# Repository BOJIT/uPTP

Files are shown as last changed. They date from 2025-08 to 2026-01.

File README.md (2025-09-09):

# uPTP

The smallest, cheapest PTP clock that you can make!

## Project Setup

1. Clone Project to your computer

2. Ensure that you have west installed somehere (I usually put it in `<GIT_REPO>/.venv`, as VSCode will usually launch it automatically.)

- `python -m venv .venv`
- `source .venv/bin/activate`
- `pip install west`

3. Run West Init Locally against the West YAML file: `west init -l software/app

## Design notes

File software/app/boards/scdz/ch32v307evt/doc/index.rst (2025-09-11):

.. zephyr:board:: ch32v307evt

Overview
********

The `SCDZ`_ CH32V307EVT hardware provides support for QingKe V4F 32-bit RISC-V
processor.

The `WCH webpage on CH32V307`_ contains
the processor's information and the datasheet.

Hardware
********

The QingKe V4F 32-bit RISC-V processor of the SCDZ CH32V307EVT is clocked by an external
8 MHz crystal or the internal 8 MHz oscillator and runs with 127 MHz.
The CH32V307 SoC features 8 USART, 5 GPIO banks, 3 SPI, 2 I2C, 2 ADC, RTC,
2 CAN, USB Host/Device, Ethernet and 4 OPA.

Supported Features
==================
- GPIO
- USART

Connections and IOs
===================

LED
---

* LED1 = Unconnected. Connect to an I/O pin (PD0).
* LED2 = Unconnected. Connect to an I/O pin (PD1).

BUTTON
------

* USER0 = Unconnected. Connect to an I/O pinn (PC0).

.. zephyr:board-supported-hw::

Programming and Debugging
*************************

Applications for the ``ch32v307evt`` board target can be built and flashed
in the usual way (see :ref:`build_an_application` and :ref:`application_run`
for more details); however, an external programmer (like the `WCH LinkE`_) is required since the board
does not have any built-in debug support.

The following pins of the external programmer must be connected to the
following pins on the PCB (best way is to use a ribbon cable):

* VCC = VCC (do not power the board from the USB port at the same time)
* GND = GND
* SWDIO = PA13
* SWCLK = PA14

Flashing
========

You can use ``minichlink`` to flash the board. Once ``minichlink`` has been set
up, build and flash applications as usual (see :ref:`build_an_application` and
:ref:`application_run` for more details).

Here is an example for the :zephyr:code-sample:`hello_world` application.

.. zephyr-app-commands::
   :zephyr-app: samples/hello_world
   :board: ch32v307evt
   :goals: build flash

Debugging
=========

This board can be debugged via OpenOCD using the WCH openOCD liberated fork, available at https://github.com/jnk0le/openocd-wch.

References
**********

.. target-notes::

.. _WCH: http://www.wch-ic.com
.. _WCH webpage on CH32V307: https://www.wch-ic.com/products/CH32V307.html
.. _WCH LinkE: https://www.wch-ic.com/products/WCH-Link.html

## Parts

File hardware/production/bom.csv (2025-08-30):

Designator | Footprint | Quantity | Value | LCSC Part #
C1, C15 | 0603 | 2 | 10u | C19702
C10, C16, C17, C18, C19, C2, C20, C21, C22, C25, C6, C7 | 0402 | 12 | 100n | C1525
C11, C9 | 0805 | 2 | 10u | C440198
C12 | 0402 | 1 | 1n | C1523
C13, C14 | 1206 | 2 | 100u | C15008
C23, C24 | 0402 | 2 | 20p | C1554
C3 | 0402 | 1 | 2.2u | C12530
C4 | 1206 | 1 | 1n | C9196
C5, C8 | 0805 | 2 | 100n | C28233
D1, D2, D3 | D_SOD-323 | 3 | BAT60JFILM | C133103
D4 | LED_WS2812B-2020_PLCC4_2.0x2.0mm | 1 | WS2812B-2020 | C965555
D5, D6 | DIO-BG-SMD_4P-L4.9-W4.0-P2.54-LS7.0-BR | 2 | MB10F_C2491 | C2491
D7, D8 | D_SMA | 2 | SS210 | C14996
D9 | SOT-23-6_L2.9-W1.6-P0.95-LS2.8-BL | 1 | USBLC6-2SC6 | C7519
FB1, FB2 | 0603 | 2 | GZ1608D601TF | C1002
J1 | IPEX-SMD_HC-RF-IPEX0303-01 | 1 | PPS_UFL | C2894919
J5 | RJ45-SMD_HC-RJ45-055-7_1 | 1 | HC-RJ45-055-7 | C3000213
L1 | L_Changjiang_FXL0630 | 1 | 47u | C475913
R1, R2, R3, R4, R6 | 0402 | 5 | 75 | C25133
R10 | 0402 | 1 | 1.2 | C2998063
R13, R5 | 0402 | 2 | 24k | C25769
R14 | 0402 | 1 | 4.3k | C25899
R15 | 0402 | 1 | 12k | C25752
R16, R17 | 0402 | 2 | 10k | C25744
R18 | 0402 | 1 | 10 | C25077
R19, R20 | 0402 | 2 | 5.1k | C25905
R7 | 0402 | 1 | 88.7k | C170366
TR1 | B1608S | 1 | Ethernet Magnetics | C507596
U1 | SOT-23-3 | 1 | XC6206P332MR-G | C5446
U2 | QFN-20-1EP_4x4mm_P0.5mm_EP2.6x2.6mm | 1 | SI3404-A-GMR | C461934
U3 | QFN-68_L8.0-W8.0-P0.40-BL-EP6.7 | 1 | CH32V307WCU6 | C5142795
USB1 | USB-C-SMD_TYPE-C-16PIN | 1 | TYPE-C 16PIN 2MD(073) | C2765186
X1 | CRYSTAL-SMD_L5.0-W3.2 | 1 | X50328MSB2GI | C115962

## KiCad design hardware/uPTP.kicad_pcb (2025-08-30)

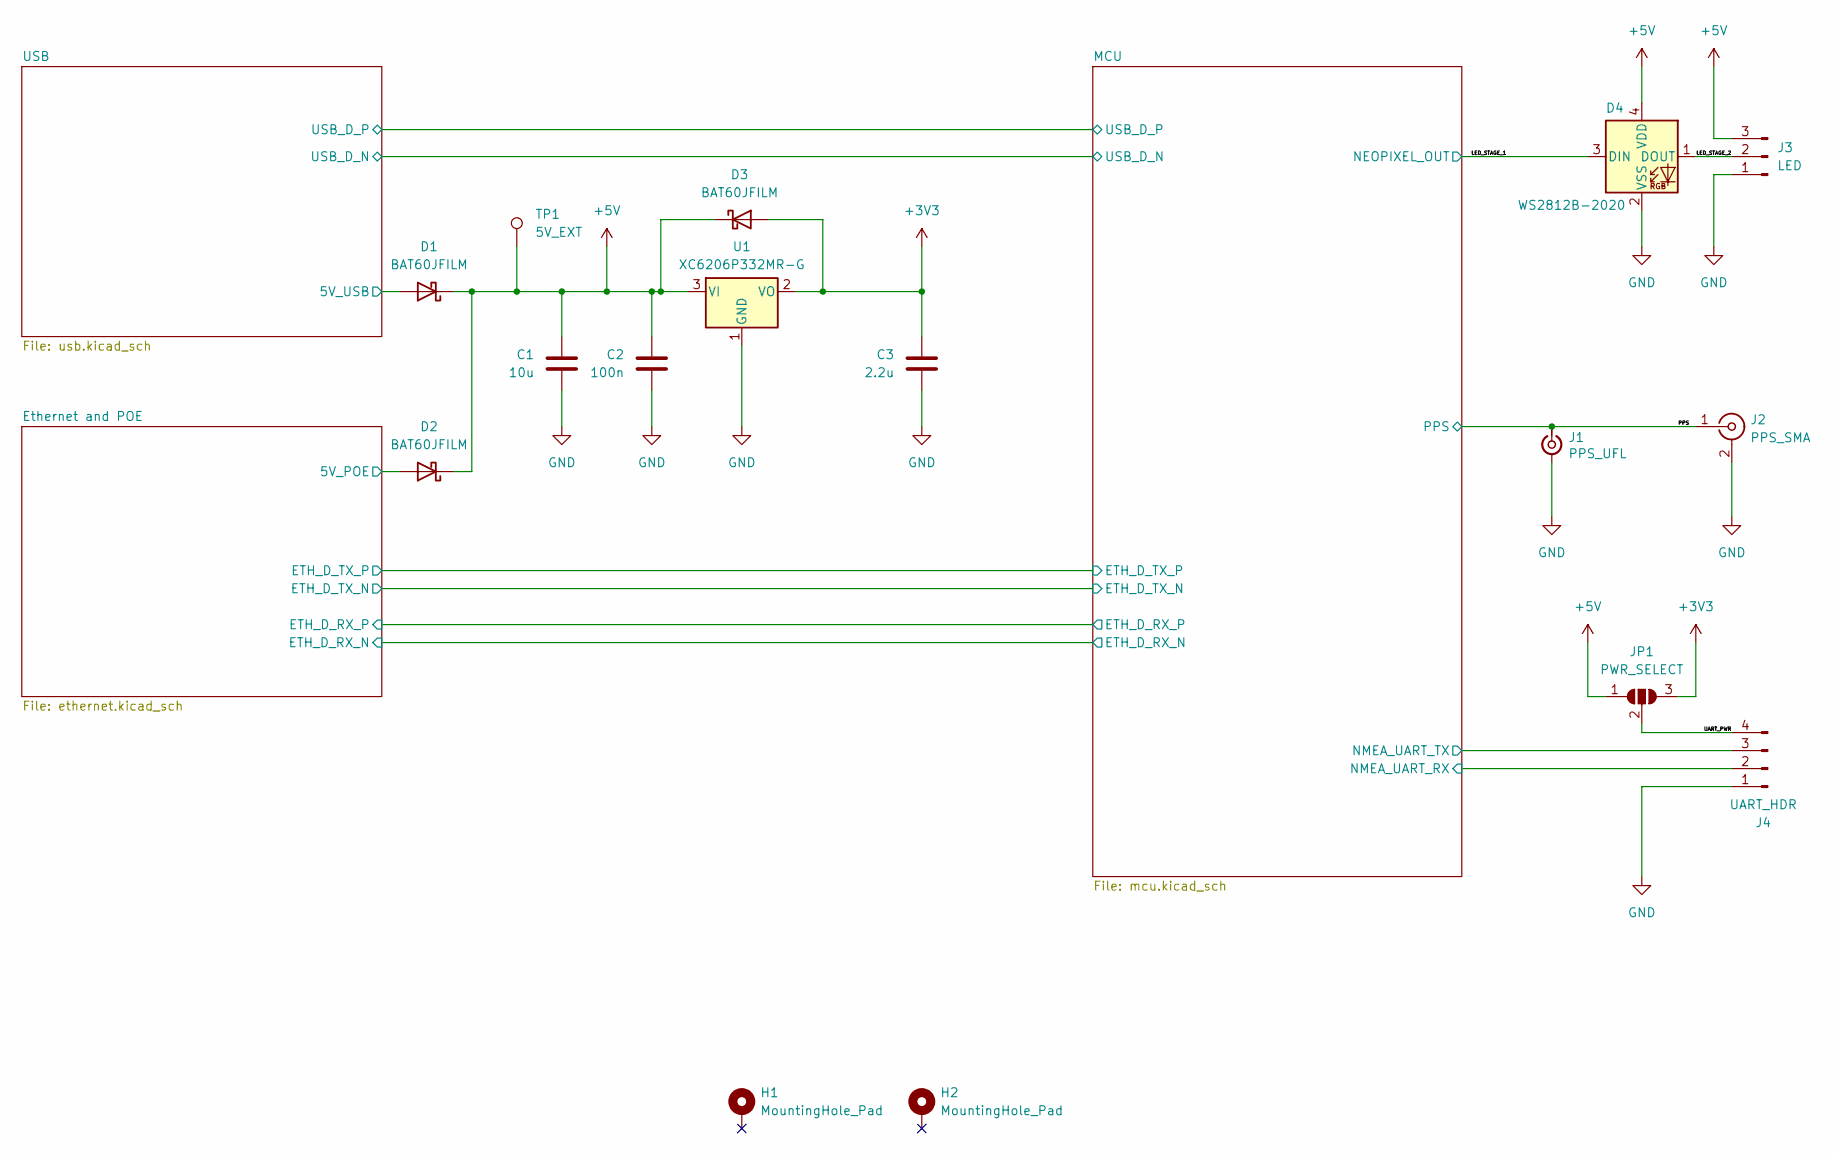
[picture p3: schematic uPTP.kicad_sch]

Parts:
C1: 10u; C_0603_1608Metric; LCSC Part C19702
C2: 100n; C_0402_1005Metric; LCSC Part C1525
C3: 2.2u; C_0402_1005Metric; LCSC Part C12530
D1, D2, D3: BAT60JFILM; D_SOD-323; LCSC Part C133103
D4: WS2812B-2020; LED_WS2812B-2020_PLCC4_2.0x2.0mm; LCSC Part C965555
H1, H2: MountingHole_Pad; MountingHole_3.2mm_M3_Pad
J1: PPS_UFL; IPEX-SMD_HC-RF-IPEX0303-01; LCSC Part C2894919
J2: PPS_SMA; SMA_Samtec_SMA-J-P-H-ST-EM1_EdgeMount
J3: LED; PinHeader_1x03_P1.27mm_Vertical
J4: UART_HDR; PinHeader_1x04_P2.54mm_Horizontal
JP1: PWR_SELECT; SolderJumper-3_P1.3mm_Open_RoundedPad1.0x1.5mm_NumberLabels
TP1: 5V_EXT; TestPoint_Pad_D1.5mm
U1: XC6206P332MR-G; SOT-23-3; LCSC Part C5446

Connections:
+3V3: C3.1, D3.2 (A), JP1.3 (B), U1.2 (VO); also elsewhere on the board
+5V: C1.1, C2.1, D1.1 (K), D2.1 (K), D3.1 (K), D4.4 (VDD), J3.3, JP1.1 (A), TP1.1, U1.3 (VI)
+5V_USB: D1.2 (A); also elsewhere on the board
/Ethernet and POE/ETH_POE_FILT_P: D2.2 (A); also elsewhere on the board
/LED_STAGE_1: D4.3 (DIN); also elsewhere on the board
/LED_STAGE_2: D4.1 (DOUT), J3.2
/MCU/NMEA_UART_RX: J4.2; also elsewhere on the board
/MCU/NMEA_UART_TX: J4.3; also elsewhere on the board
/PPS: J1.1 (In), J2.1 (In); also elsewhere on the board
/UART_PWR: J4.4, JP1.2 (C)
GND: C1.2, C2.2, C3.2, D4.2 (VSS), J1.2 (Ext), J2.2 (Ext), J3.1, J4.1, U1.1 (GND); also elsewhere on the board

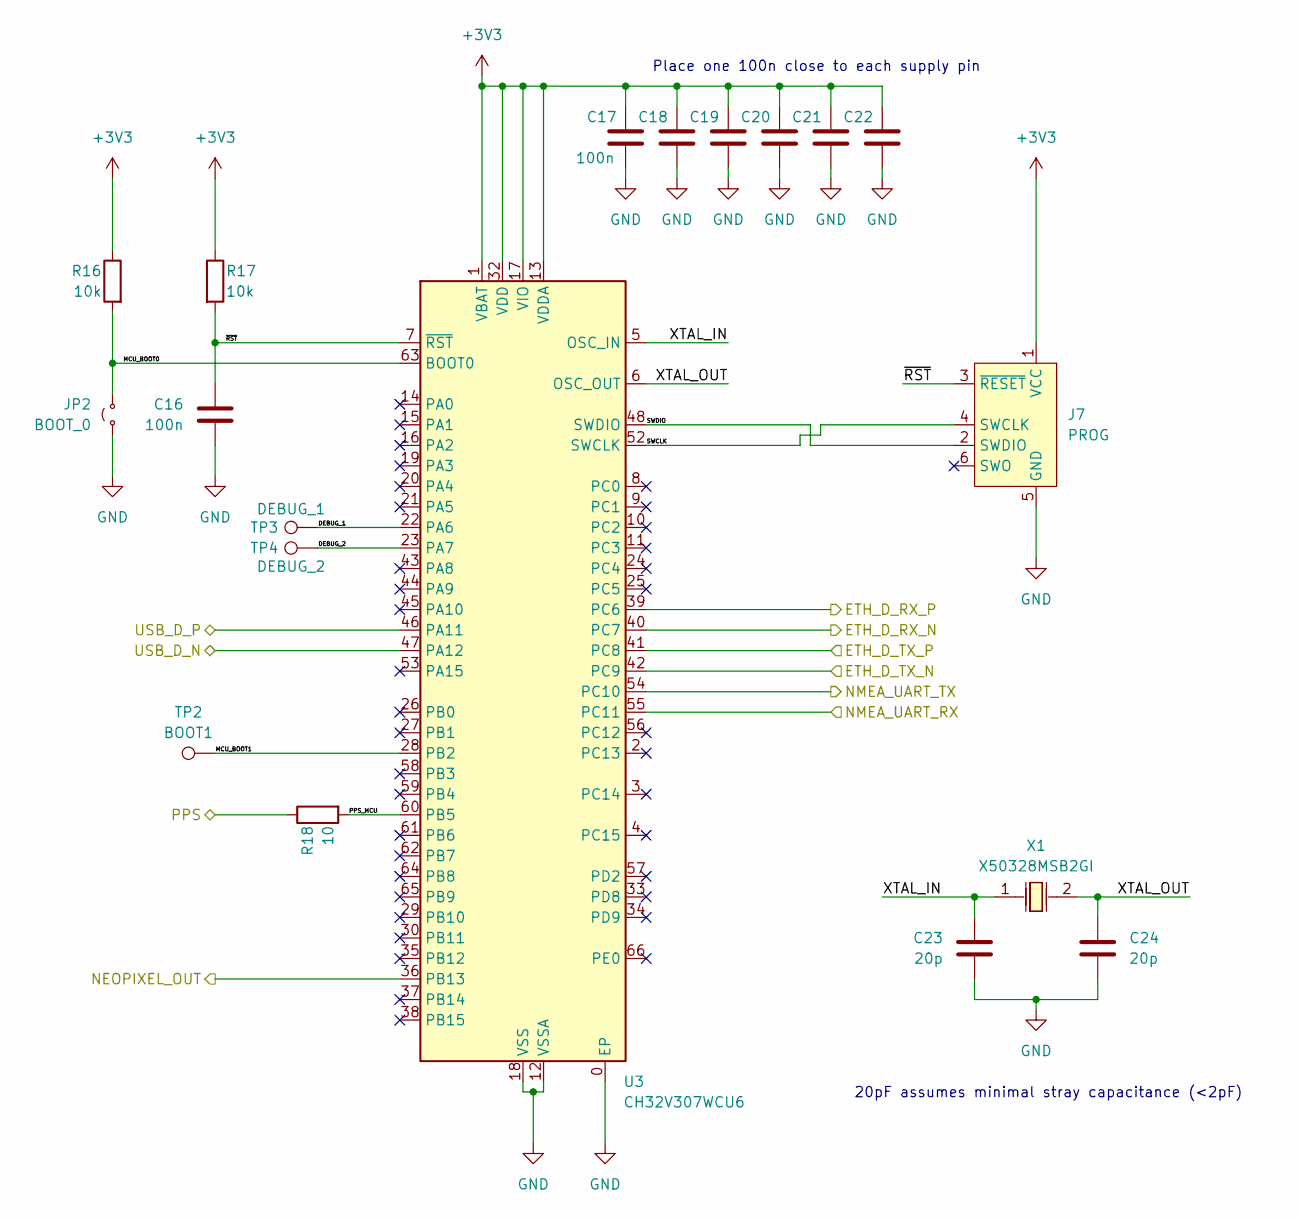
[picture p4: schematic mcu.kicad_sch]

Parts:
C16, C17, C18, C19, C20, C21, C22: 100n; C_0402_1005Metric; LCSC Part C1525
C23, C24: 20p; C_0402_1005Metric; LCSC Part C1554
J7: PROG; Tag-Connect_TC2030-IDC-NL_2x03_P1.27mm_Vertical
JP2: BOOT_0; SolderJumper-2_P1.3mm_Open_RoundedPad1.0x1.5mm
R16, R17: 10k; R_0402_1005Metric; LCSC Part C25744
R18: 10; R_0402_1005Metric; LCSC Part C25077
TP2: BOOT1; TestPoint_Pad_D1.5mm
TP3: DEBUG_1; TestPoint_Pad_D1.5mm
TP4: DEBUG_2; TestPoint_Pad_D1.5mm
U3: CH32V307WCU6; QFN-68_L8.0-W8.0-P0.40-BL-EP6.7; LCSC Part C5142795
X1: X50328MSB2GI; CRYSTAL-SMD_L5.0-W3.2; LCSC Part C115962

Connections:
+3V3: C17.1, C18.1, C19.1, C20.1, C21.1, C22.1, J7.1 (VCC), R16.1, R17.1, U3.1 (VBAT), U3.13 (VDDA), U3.17 (VIO), U3.31 (VIO), U3.32 (VDD), U3.50 (VDD), U3.51 (VIO), U3.67 (VIO), U3.68 (VDD); also elsewhere on the board
/Ethernet and POE/ETH_D_RX_N: U3.40 (PC7); also elsewhere on the board
/Ethernet and POE/ETH_D_RX_P: U3.39 (PC6); also elsewhere on the board
/Ethernet and POE/ETH_D_TX_N: U3.42 (PC9); also elsewhere on the board
/Ethernet and POE/ETH_D_TX_P: U3.41 (PC8); also elsewhere on the board
/LED_STAGE_1: U3.36 (PB13); also elsewhere on the board
/MCU/DEBUG_1: TP3.1, U3.22 (PA6)
/MCU/DEBUG_2: TP4.1, U3.23 (PA7)
/MCU/MCU_BOOT0: JP2.2 (B), R16.2, U3.63 (BOOT0)
/MCU/MCU_BOOT1: TP2.1, U3.28 (PB2)
/MCU/NMEA_UART_RX: U3.55 (PC11); also elsewhere on the board
/MCU/NMEA_UART_TX: U3.54 (PC10); also elsewhere on the board
/MCU/PPS_MCU: R18.2, U3.60 (PB5)
/MCU/SWCLK: J7.4 (SWCLK), U3.52 (SWCLK)
/MCU/SWDIO: J7.2 (SWDIO), U3.48 (SWDIO)
/MCU/USB_D_N: U3.47 (PA12); also elsewhere on the board
/MCU/USB_D_P: U3.46 (PA11); also elsewhere on the board
/MCU/XTAL_IN: C23.1, U3.5 (OSC_IN), X1.1
/MCU/XTAL_OUT: C24.1, U3.6 (OSC_OUT), X1.2
/MCU/~RST: C16.1, J7.3 (~RESET), R17.2, U3.7 (~RST)
/PPS: R18.1; also elsewhere on the board
GND: C16.2, C17.2, C18.2, C19.2, C20.2, C21.2, C22.2, C23.2, C24.2, J7.5 (GND), JP2.1 (A), U3.0 (EP), U3.12 (VSSA), U3.18 (VSS), U3.49 (VSS), U3.69 (VSS); also elsewhere on the board

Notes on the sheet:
20pF assumes minimal stray capacitance (<2pF)
Place one 100n close to each supply pin

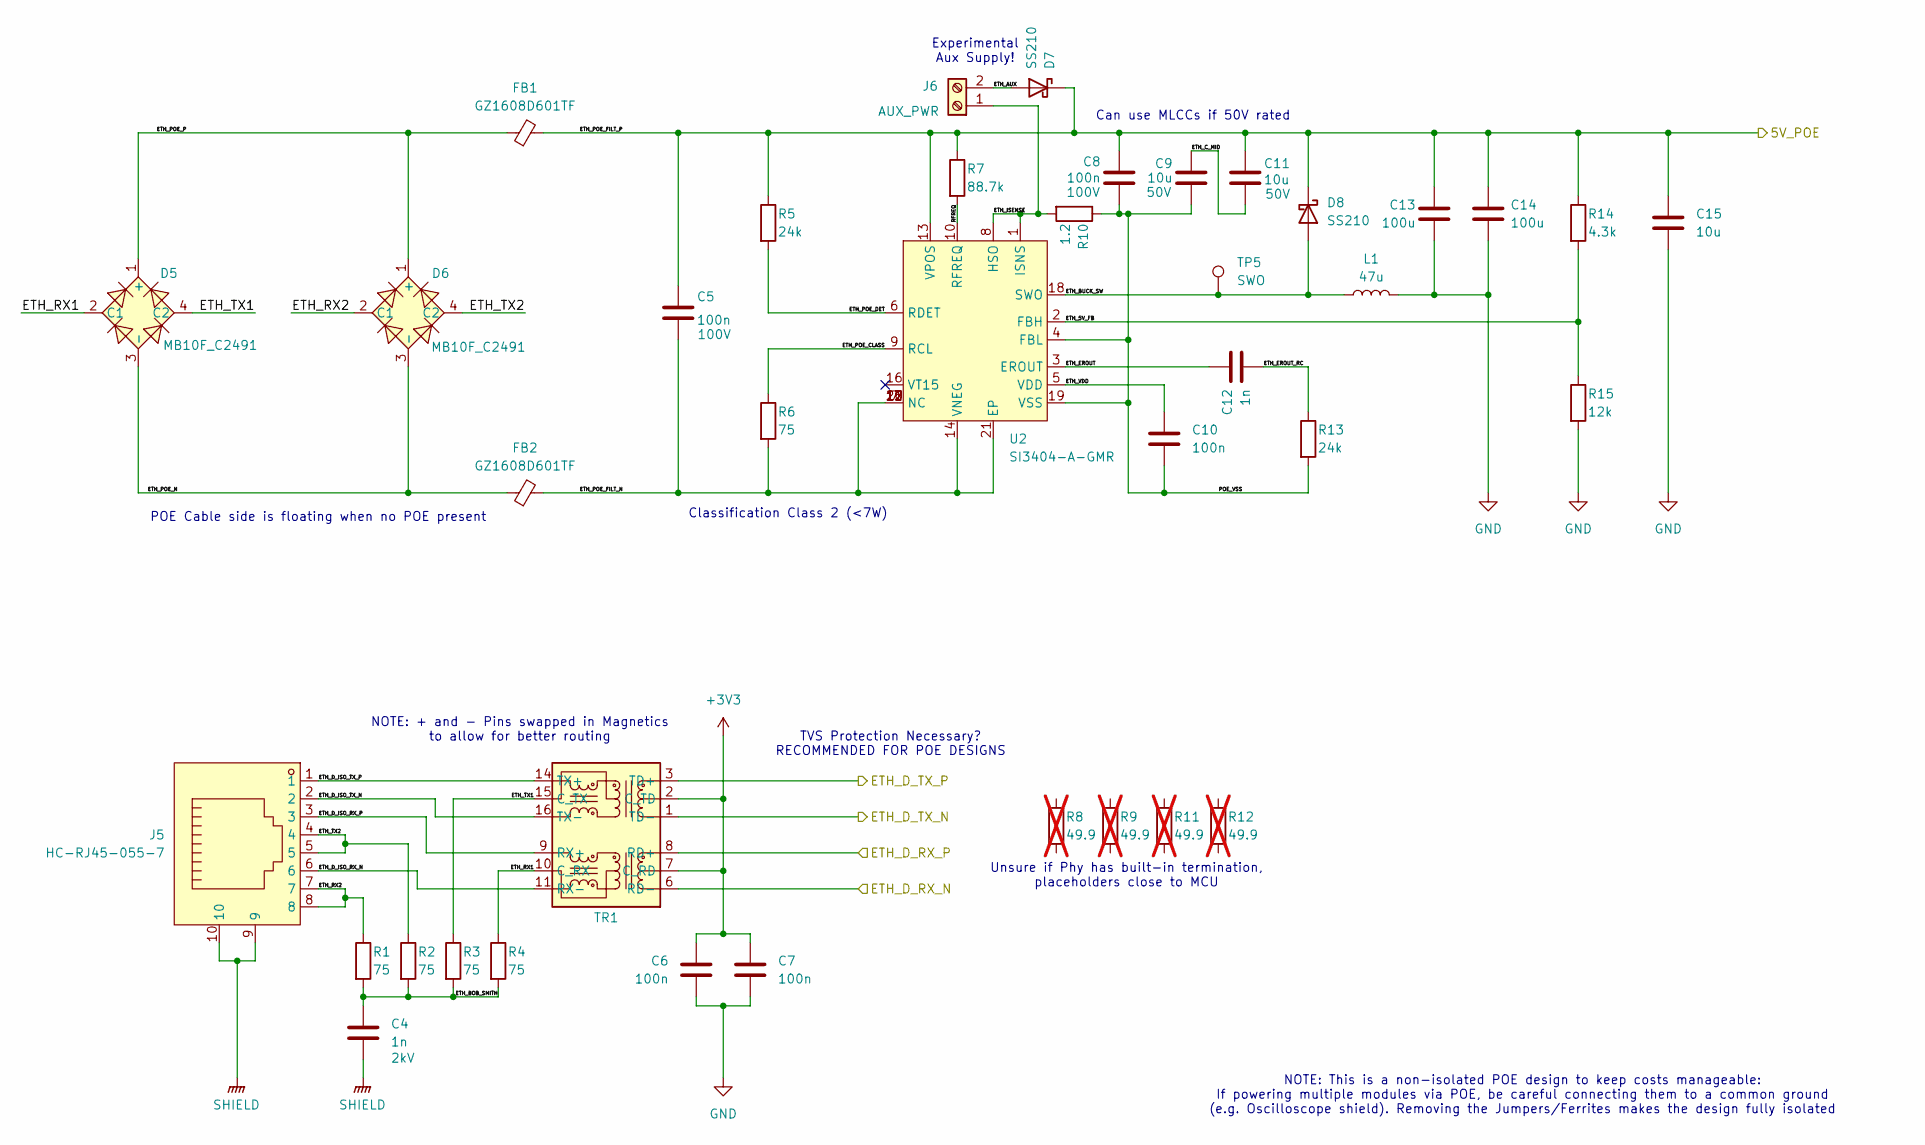
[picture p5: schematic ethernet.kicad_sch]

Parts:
C4: 1n; C_1206_3216Metric; LCSC Part C9196
C5, C8: 100n; C_0805_2012Metric; LCSC Part C28233
C6, C7, C10: 100n; C_0402_1005Metric; LCSC Part C1525
C9, C11: 10u; C_0805_2012Metric; LCSC Part C440198
C12: 1n; C_0402_1005Metric; LCSC Part C1523
C13, C14: 100u; C_1206_3216Metric; LCSC Part C15008
C15: 10u; C_0603_1608Metric; LCSC Part C19702
D5, D6: MB10F_C2491; DIO-BG-SMD_4P-L4.9-W4.0-P2.54-LS7.0-BR; LCSC Part C2491
D7, D8: SS210; D_SMA; LCSC Part C14996
FB1, FB2: GZ1608D601TF; R_0603_1608Metric; LCSC Part C1002
J5: HC-RJ45-055-7; RJ45-SMD_HC-RJ45-055-7_1; LCSC Part C3000213
J6: AUX_PWR; TerminalBlock_Phoenix_MPT-0,5-2-2.54_1x02_P2.54mm_Horizontal
L1: 47u; L_Changjiang_FXL0630; LCSC Part C475913
R1, R2, R3, R4, R6: 75; R_0402_1005Metric; LCSC Part C25133
R5, R13: 24k; R_0402_1005Metric; LCSC Part C25769
R7: 88.7k; R_0402_1005Metric; LCSC Part C170366
R8, R9, R11, R12: 49.9; R_0402_1005Metric; not fitted
R10: 1.2; R_0402_1005Metric; LCSC Part C2998063
R14: 4.3k; R_0402_1005Metric; LCSC Part C25899
R15: 12k; R_0402_1005Metric; LCSC Part C25752
TP5: SWO; TestPoint_Pad_D1.5mm
TR1: Ethernet Magnetics; B1608S; LCSC Part C507596
U2: SI3404-A-GMR; QFN-20-1EP_4x4mm_P0.5mm_EP2.6x2.6mm; LCSC Part C461934

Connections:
+3V3: C6.1, C7.1, TR1.2 (C_TD), TR1.7 (C_RD); also elsewhere on the board
/Ethernet and POE/ETH_5V_FB: R14.2, R15.1, U2.2 (FBH)
/Ethernet and POE/ETH_AUX: D7.2 (A), J6.2
/Ethernet and POE/ETH_BOB_SMITH: C4.1, R1.2, R2.2, R3.2, R4.2
/Ethernet and POE/ETH_BUCK_SW: D8.2 (A), L1.1, TP5.1, U2.18 (SWO)
/Ethernet and POE/ETH_C_MID: C9.1, C11.2
/Ethernet and POE/ETH_D_ISO_RX_N: J5.6, TR1.11 (RX-)
/Ethernet and POE/ETH_D_ISO_RX_P: J5.3, TR1.9 (RX+)
/Ethernet and POE/ETH_D_ISO_TX_N: J5.2, TR1.16 (TX-)
/Ethernet and POE/ETH_D_ISO_TX_P: J5.1, TR1.14 (TX+)
/Ethernet and POE/ETH_D_RX_N: TR1.6 (RD-); also elsewhere on the board
/Ethernet and POE/ETH_D_RX_P: TR1.8 (RD+); also elsewhere on the board
/Ethernet and POE/ETH_D_TX_N: TR1.1 (TD-); also elsewhere on the board
/Ethernet and POE/ETH_D_TX_P: TR1.3 (TD+); also elsewhere on the board
/Ethernet and POE/ETH_EROUT: C12.1, U2.3 (EROUT)
/Ethernet and POE/ETH_EROUT_RC: C12.2, R13.1
/Ethernet and POE/ETH_ISENSE: J6.1, R10.2, U2.1 (ISNS), U2.8 (HSO)
/Ethernet and POE/ETH_POE_CLASS: R6.1, U2.9 (RCL)
/Ethernet and POE/ETH_POE_DET: R5.2, U2.6 (RDET)
/Ethernet and POE/ETH_POE_FILT_N: C5.2, FB2.2, R6.2, U2.7 (NC), U2.11 (NC), U2.12 (NC), U2.14 (VNEG), U2.15 (NC), U2.17 (NC), U2.20 (NC), U2.21 (EP)
/Ethernet and POE/ETH_POE_FILT_P: C5.1, C8.1, C11.1, C13.1, C14.1, C15.1, D7.1 (K), D8.1 (K), FB1.2, R5.1, R7.1, R14.1, U2.13 (VPOS); also elsewhere on the board
/Ethernet and POE/ETH_POE_N: D5.3 (-), D6.3 (-), FB2.1
/Ethernet and POE/ETH_POE_P: D5.1 (+), D6.1 (+), FB1.1
/Ethernet and POE/ETH_RX1: D5.2 (C1), R4.1, TR1.10 (C_RX)
/Ethernet and POE/ETH_RX2: D6.2 (C1), J5.7, J5.8, R1.1
/Ethernet and POE/ETH_TX1: D5.4 (C2), R3.1, TR1.15 (C_TX)
/Ethernet and POE/ETH_TX2: D6.4 (C2), J5.4, J5.5, R2.1
/Ethernet and POE/ETH_VDD: C10.1, U2.5 (VDD)
/Ethernet and POE/POE_VSS: C8.2, C9.2, C10.2, R10.1, R13.2, U2.4 (FBL), U2.19 (VSS)
/Ethernet and POE/RFREQ: R7.2, U2.10 (RFREQ)
GND: C6.2, C7.2, C13.2, C14.2, C15.2, L1.2, R15.2; also elsewhere on the board
SHIELD: C4.2, J5.9, J5.10

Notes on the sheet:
Experimental Aux Supply!
POE Cable side is floating when no POE present
TVS Protection Necessary? RECOMMENDED FOR POE DESIGNS
NOTE: + and - Pins swapped in Magnetics to allow for better routing
Classification Class 2 (<7W)
Can use MLCCs if 50V rated
NOTE: This is a non-isolated POE design to keep costs manageable: If powering multiple modules via POE, be careful connecting them to a common ground (e.g. Oscilloscope shield). Removing the Jumpers/Ferrites makes the design fully isolated
Unsure if Phy has built-in termination, placeholders close to MCU

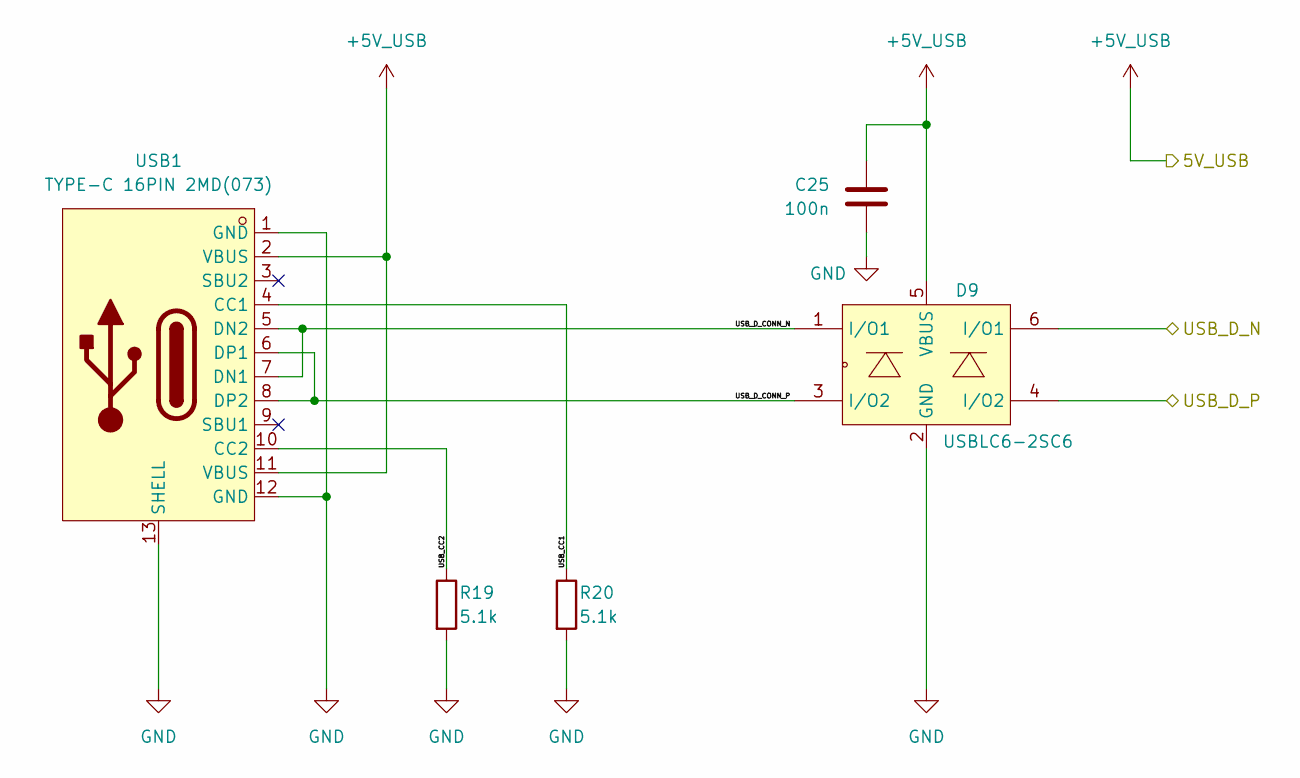
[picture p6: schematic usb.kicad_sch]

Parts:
C25: 100n; C_0402_1005Metric; LCSC Part C1525
D9: USBLC6-2SC6; SOT-23-6_L2.9-W1.6-P0.95-LS2.8-BL; LCSC Part C7519
R19, R20: 5.1k; R_0402_1005Metric; LCSC Part C25905
USB1: TYPE-C 16PIN 2MD(073); USB-C-SMD_TYPE-C-16PIN; LCSC Part C2765186

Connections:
+5V_USB: C25.1, D9.5 (VBUS), USB1.2 (VBUS), USB1.11 (VBUS); also elsewhere on the board
/MCU/USB_D_N: D9.6 (I/O1); also elsewhere on the board
/MCU/USB_D_P: D9.4 (I/O2); also elsewhere on the board
/USB/USB_CC1: R20.1, USB1.4 (CC1)
/USB/USB_CC2: R19.1, USB1.10 (CC2)
/USB/USB_D_CONN_N: D9.1 (I/O1), USB1.5 (DN2), USB1.7 (DN1)
/USB/USB_D_CONN_P: D9.3 (I/O2), USB1.6 (DP1), USB1.8 (DP2)
GND: C25.2, D9.2 (GND), R19.2, R20.2, USB1.1 (GND), USB1.12 (GND), USB1.13 (SHELL); also elsewhere on the board

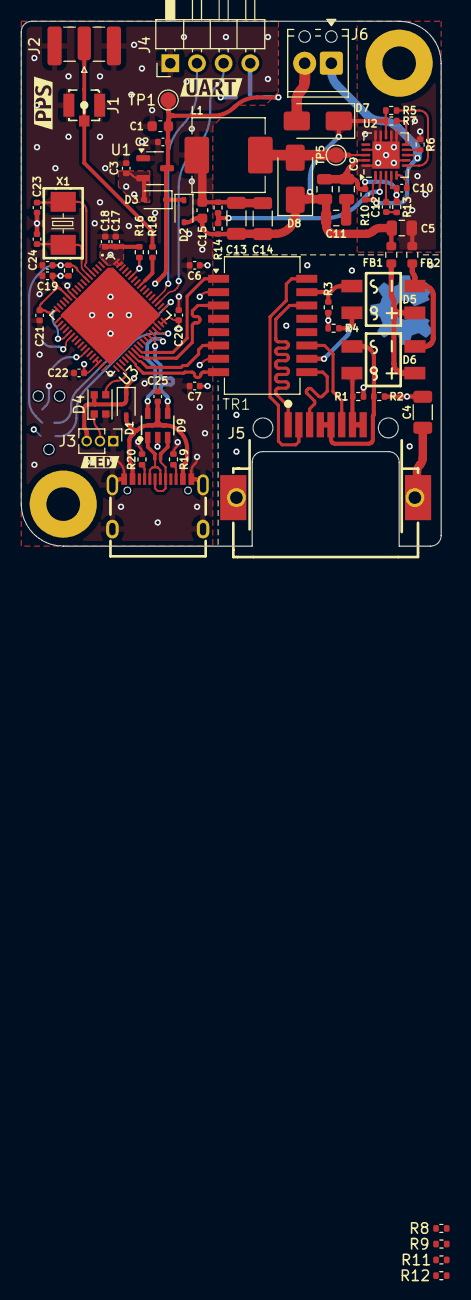
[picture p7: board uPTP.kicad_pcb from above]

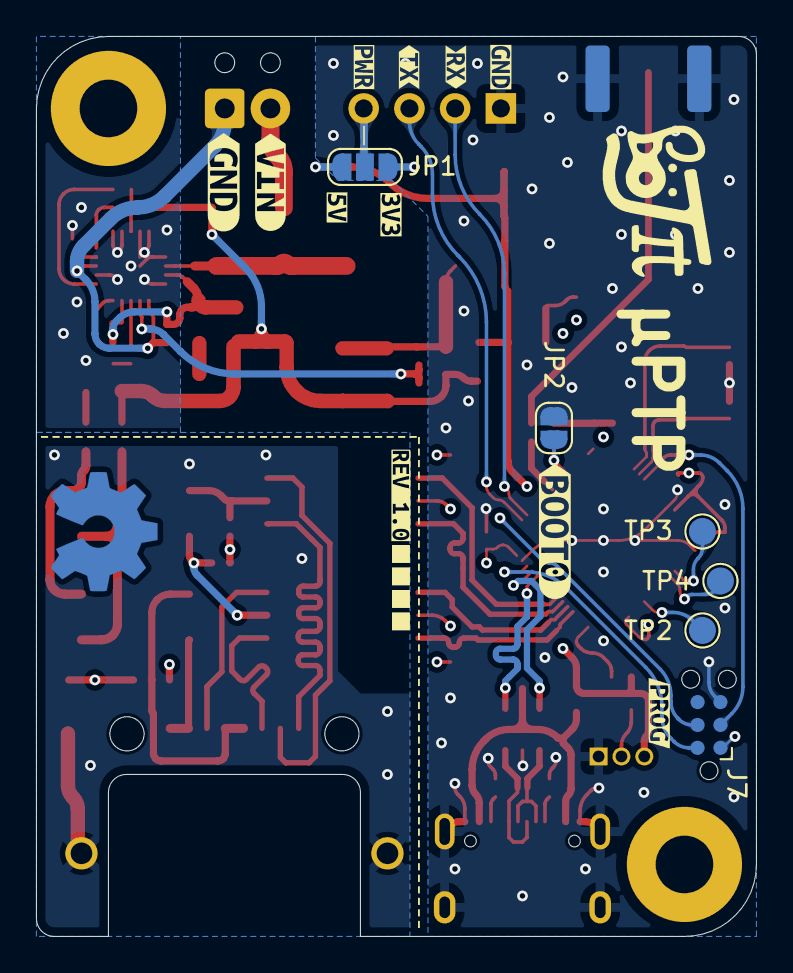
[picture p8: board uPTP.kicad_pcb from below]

Board: 4 copper layers, 40.0 x 50.0 mm, 93 parts (17 on the bottom side), 56 nets.

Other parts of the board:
kibuzzard-68B2C77A: G***; kibuzzard-68B2C77A
kibuzzard-68B2C79E: G***; kibuzzard-68B2C79E
kibuzzard-68B2D2A2: G***; kibuzzard-68B2D2A2
kibuzzard-68B2D2B0: G***; kibuzzard-68B2D2B0
kibuzzard-68B2D2D8: G***; kibuzzard-68B2D2D8
kibuzzard-68B2D2E2: G***; kibuzzard-68B2D2E2
kibuzzard-68B2D3F7: G***; kibuzzard-68B2D3F7
kibuzzard-68B2D9A3: G***; kibuzzard-68B2D9A3
kibuzzard-68B2D28B: G***; kibuzzard-68B2D28B
kibuzzard-68B2D264: G***; kibuzzard-68B2D264
kibuzzard-68B2D304: G***; kibuzzard-68B2D304
kibuzzard-68B2D348: G***; kibuzzard-68B2D348
kibuzzard-68B2D367: G***; kibuzzard-68B2D367
kibuzzard-68B2D434: G***; kibuzzard-68B2D434

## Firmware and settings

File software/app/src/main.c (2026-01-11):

/**
 * @file main.c
 * @author James Bennion-Pedley
 * @brief Main entry point for application
 * @date 01/06/2025
 *
 * @copyright Copyright (c) 2025
 *
 */

/*--------------------------------- Includes ---------------------------------*/

#include <errno.h>
#include <zephyr/drivers/led_strip.h>
#include <zephyr/kernel.h>
#include <zephyr/logging/log.h>

#include "threads/net_mgr.h"

/*---------------------------- Macros & Constants ----------------------------*/

LOG_MODULE_REGISTER(main, CONFIG_LOG_DEFAULT_LEVEL);

#define LED_STRIP_NODE DT_NODELABEL(led_strip)

struct led_rgb m_colours[3] = {
	{
		.r = 0x50,
		.g = 0x50,
		.b = 0x00,
	},
	{
		.r = 0x00,
		.g = 0x50,
		.b = 0x50,
	},
	{
		.r = 0x50,
		.g = 0x00,
		.b = 0x50,
	},
};

/*----------------------------------- State ----------------------------------*/

K_THREAD_STACK_DEFINE(m_net_mgr_stack, 2048);
struct k_thread m_net_mgr_thread;

/*------------------------------ Private Functions ---------------------------*/

/*------------------------------- Public Functions ---------------------------*/

/*-------------------------------- Entry Point -------------------------------*/

int main(void)
{
	static const struct device *strip = DEVICE_DT_GET_OR_NULL(LED_STRIP_NODE);

	if (!strip || !device_is_ready(strip)) {
		LOG_ERR("LED device not ready");
		return -EIO;
	}

	net_mgr_init();
	k_thread_create(&m_net_mgr_thread, m_net_mgr_stack, K_THREAD_STACK_SIZEOF(m_net_mgr_stack),
			net_mgr_thread, NULL, NULL, NULL, 5, 0, K_NO_WAIT);

	size_t i = 0;
	while (1) {
		if (strip) {
			led_strip_update_rgb(strip, &m_colours[i], 1);
			i = (i + 1) % ARRAY_SIZE(m_colours);
		}

		k_msleep(1000);
	}
}

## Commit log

2025-06-01 Add first files
    [uPTP.kicad_pcb, uPTP.kicad_sch]
2025-06-01 Key components
    [uPTP.kicad_pcb, uPTP.kicad_sch]
2025-06-03 Some more handy components
    [uPTP.kicad_pcb, uPTP.kicad_sch]
2025-06-03 Add magnetics
    [uPTP.kicad_pcb, uPTP.kicad_sch]
2025-06-03 Nice first render
    [uPTP.kicad_pcb, uPTP.kicad_sch]
2025-06-04 POE CTRL?
    [uPTP.kicad_pcb, uPTP.kicad_sch]
2025-06-04 Backup progress
    [ethernet.kicad_sch, power.kicad_sch, uPTP.kicad_pcb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]
2025-06-05 POE layout considerationa
    [ethernet.kicad_sch, uPTP.kicad_pcb]
2025-06-06 Vaguely convincing render...
    [ethernet.kicad_sch, power.kicad_sch, uPTP.kicad_pcb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]
2025-06-06 Component selection mostly done
    [power.kicad_sch, uPTP.kicad_pcb, uPTP.kicad_sch]
2025-06-06 Done for the day
    [uPTP.kicad_pcb, uPTP.kicad_sch]
2025-07-09 Prep for change to SI3404 https://www.skyworksinc.com/-/media/Skyworks/SL/documents/public/application-notes/an1130-si3404-06x-dg.pdf
    [ethernet.kicad_sch, power.kicad_sch, uPTP.kicad_pcb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]
2025-07-11 Add SI3404 part
    [ethernet.kicad_sch, uPTP.kicad_pcb]
2025-07-12 Add XTAL, rough POE Schematic
    [ethernet.kicad_sch, uPTP.kicad_pcb, uPTP.kicad_sch]
2025-07-13 Neaten up schematic hierarchy
    [ethernet.kicad_sch, mcu.kicad_sch, power.kicad_sch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]
2025-07-13 Confirm all part footprints, start rought layout
    [ethernet.kicad_sch, mcu.kicad_sch, power.kicad_sch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]
2025-07-13 Tidy up layout
    [ethernet.kicad_sch, mcu.kicad_sch, uPTP.kicad_pcb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]
2025-08-04 Set reqs for trace widths
    [uPTP.kicad_pcb]
2025-08-10 Change pin layout to make Ethernet Routing nicer
    [ethernet.kicad_sch, uPTP.kicad_pcb]
2025-08-29 Route one
    [uPTP.kicad_pcb]
2025-08-29 All length match
    [uPTP.kicad_pcb]
2025-08-29 ISO ETH Section Done
    [ethernet.kicad_sch, uPTP.kicad_pcb, uPTP.kicad_sch]
2025-08-29 All footprints 3D plus some more routing
    [mcu.kicad_sch, uPTP.kicad_pcb, uPTP.kicad_sch]
2025-08-29 Fix aux pwr oops
    [ethernet.kicad_sch, uPTP.kicad_pcb]
2025-08-29 Backup before relayout
    [uPTP.kicad_pcb]
2025-08-29 Correct misunderstandings, mostly there
    [ethernet.kicad_sch, uPTP.kicad_pcb, uPTP.kicad_sch]
2025-08-29 Routed board, first draft
    [uPTP.kicad_pcb]
2025-08-29 Routed, need to do DRC
    [uPTP.kicad_pcb]
2025-08-30 Clear all easy violations
    [uPTP.kicad_pcb]
2025-08-30 All DRCs cleared
    [uPTP.kicad_pcb]
2025-08-30 Artwork added
    [uPTP.kicad_pcb]
2025-08-30 Add rounded track overlay
    [uPTP-rounded.kicad_pcb]
2025-08-30 Add teardrops
    [uPTP-rounded.kicad_pcb]
2025-08-30 Re-link rounded to be default
    [ethernet.kicad_sch, mcu.kicad_sch, uPTP-Pre-Rounding.kicad_pcb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]
2025-08-30 Fix BOM entries, should be good to go
    [ethernet.kicad_sch, mcu.kicad_sch, uPTP.kicad_pcb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]
2025-08-30 Allow assembly files to be checked in
    [bom.csv, designators.csv, positions.csv]
2025-08-30 Update IBOM
    [uPTP.kicad_pcb]
2025-09-09 Basic board support template for Zephyr
2025-09-09 Custom Board Support Works!
2025-09-09 Use correct pin variant
2025-09-09 Remap uPTP hardware to new UART pins
2025-09-12 Add option to build for STM32 target too
2025-09-21 Trims to get things running on smaller RAM footprint
2025-12-14 Add Ethernet to the uPTP board - works!
2025-12-31 Add WS2812b SPI mode via test point 4 (PA7)
2026-01-01 Working SPI
2026-01-11 Disable LED strip for now, get things tested for CH32V307 ethernet PR (#2)
    * Disable LED strip for now, get things tested for CH32V307 ethernet PR
    * rename to work on case-sensitive filesystem, fix CI
    * MDNS and DNS-SD working
    * Update manifest
    * Test HW multicast filter
    * Test Ethernet Driver fixes, with LED
    [main.c]
